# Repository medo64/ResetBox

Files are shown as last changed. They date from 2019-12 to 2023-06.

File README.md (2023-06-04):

### ResetBox

This device will turn off DC power supply if a longer press on external switch
is detected. Status will be communicated on external LED.

#### Operation

Press and hold button for 2 seconds until LED decreases in brightness. Once
button is released, device will reset. If you hold button even longer (additional
10 second after LED has dimmed) power off operation will be cancelled.

#### Set Voltage

Output devices MUST be disconnected during this time unless they can handle
full 20 V.

Unplug USB cable and hold internal button while plugging it back in until ACT
LED stops blinking (about 3 seconds). No you can release button. In config mode,
press internal button once for each voltage step. Once voltage has been
selected, long press internal button to save the value. Once blinking stops,
release the button and device will start normally.

---

*You can check my blog and other projects at [www.medo64.com](https://www.medo64.com/electronics/).*

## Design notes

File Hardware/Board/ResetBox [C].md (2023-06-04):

### ResetBox

Board size: 56.6 x 57.7 mm ~ 4.3 sqin
Voltage: 5-20 V
Current: 3A

#### Parts

|  # | Part | RefDes  | Part Number |
|---:|---|---|---|
|  3 | C 100nF X7R 25V (0805) | C1-C3 | 478-5311-1-ND |
|  2 | C 2.2uF X7R 100V (1206) | C4-C5 | 478-12481-1-ND |
|  8 | DS LED (0805) | DS1-DS8 | 475-1415-1-ND |
|  1 | J USB C 2.0, horizontal | J1 | 2073-USB4085-GF-ACT-ND |
|  2 | J Barrel 2.1x5.5mm | J2-J3 | 839-1514-ND |
| /2 | J MC 1,5/ 2-G-3,81 (2w) *OPTIONAL* | (J2-J3) | ED2808-ND |
|  2 | J Barrel 2.1x5.5mm | J2-J3 | 839-1514-ND |
|  1 | J JST S3B-XH-A (3w) | J4 | 455-2250-ND |
|  1 | Q NPN 40V 100mA (SOT-23) | Q1 | MMBT3904TPMSCT-ND |
|  1 | Q P-MOSFET 30V 4A (SOT-23) | Q1 | DMP3099L-13DICT-ND |
|  1 | R 470 5% 0.125W (0805) | R1 | RMCF0805JT470R |
| 10 | R 3.3K 5% 0.125W (0805) | R2-R11  | RMCF0805JT3K30 |
|  4 | R 10K 5% 0.125W (0805) | R12-R15 | RMCF0805JT10K0 |
|  1 | S Tactile SPST-NO (6x6mm) | S1 | 450-1647-ND |
|  1 | U PIC12F1501-I/SN (SOIC-8) | U1 | PIC12F1501-I/SN-ND |
|  1 | U 74HC238D (SOIC-16) | U2 | 74HC238DCT-ND |
|  1 | VR 3V3 (SOT23-3 B) | VR1 | AP7380-33Y-13DICT-ND |
|  1 | VR CH224K | VR2 | |
|  1 | H 1593KBK | | HM355-ND |
|  4 | H PCB Screw Self-tapping M3 6mm (#4 1/4") | | SR6004-ND |
|  1 | S Momentary {560} | | 1528-2542-ND |
| /2 | P MC 1,5/ 4-ST-3,81 (2w) *OPTIONAL* | | ED2875-ND |

#### Alternative Connectors

As alternative to barrel connectors, one can use block headers. Either one or
the other should be used.

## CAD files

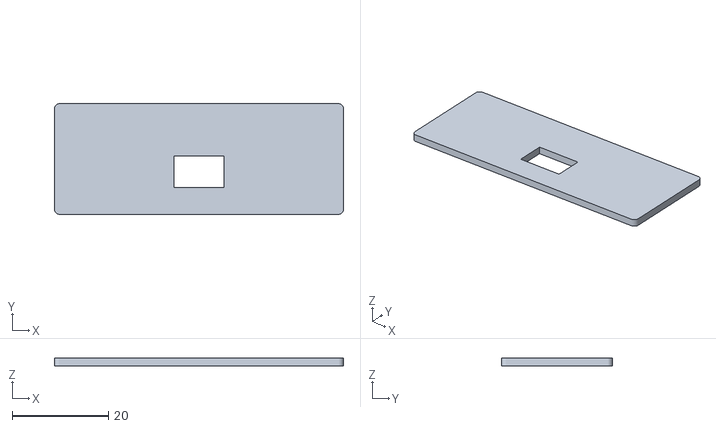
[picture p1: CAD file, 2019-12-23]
Hardware/Board/ResetBox Panel (Front).stl
60.0 x 23.0 x 1.60

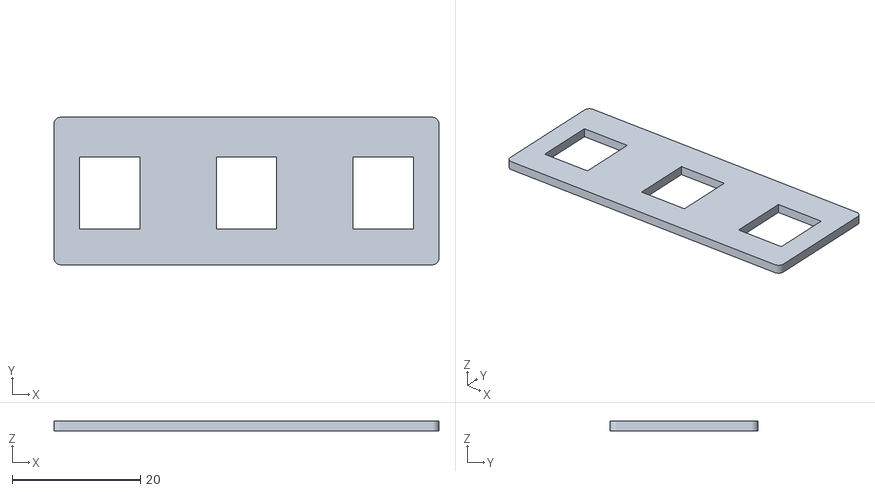
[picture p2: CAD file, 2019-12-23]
Hardware/Board/ResetBox Panel (Back).stl
60.0 x 23.0 x 1.60

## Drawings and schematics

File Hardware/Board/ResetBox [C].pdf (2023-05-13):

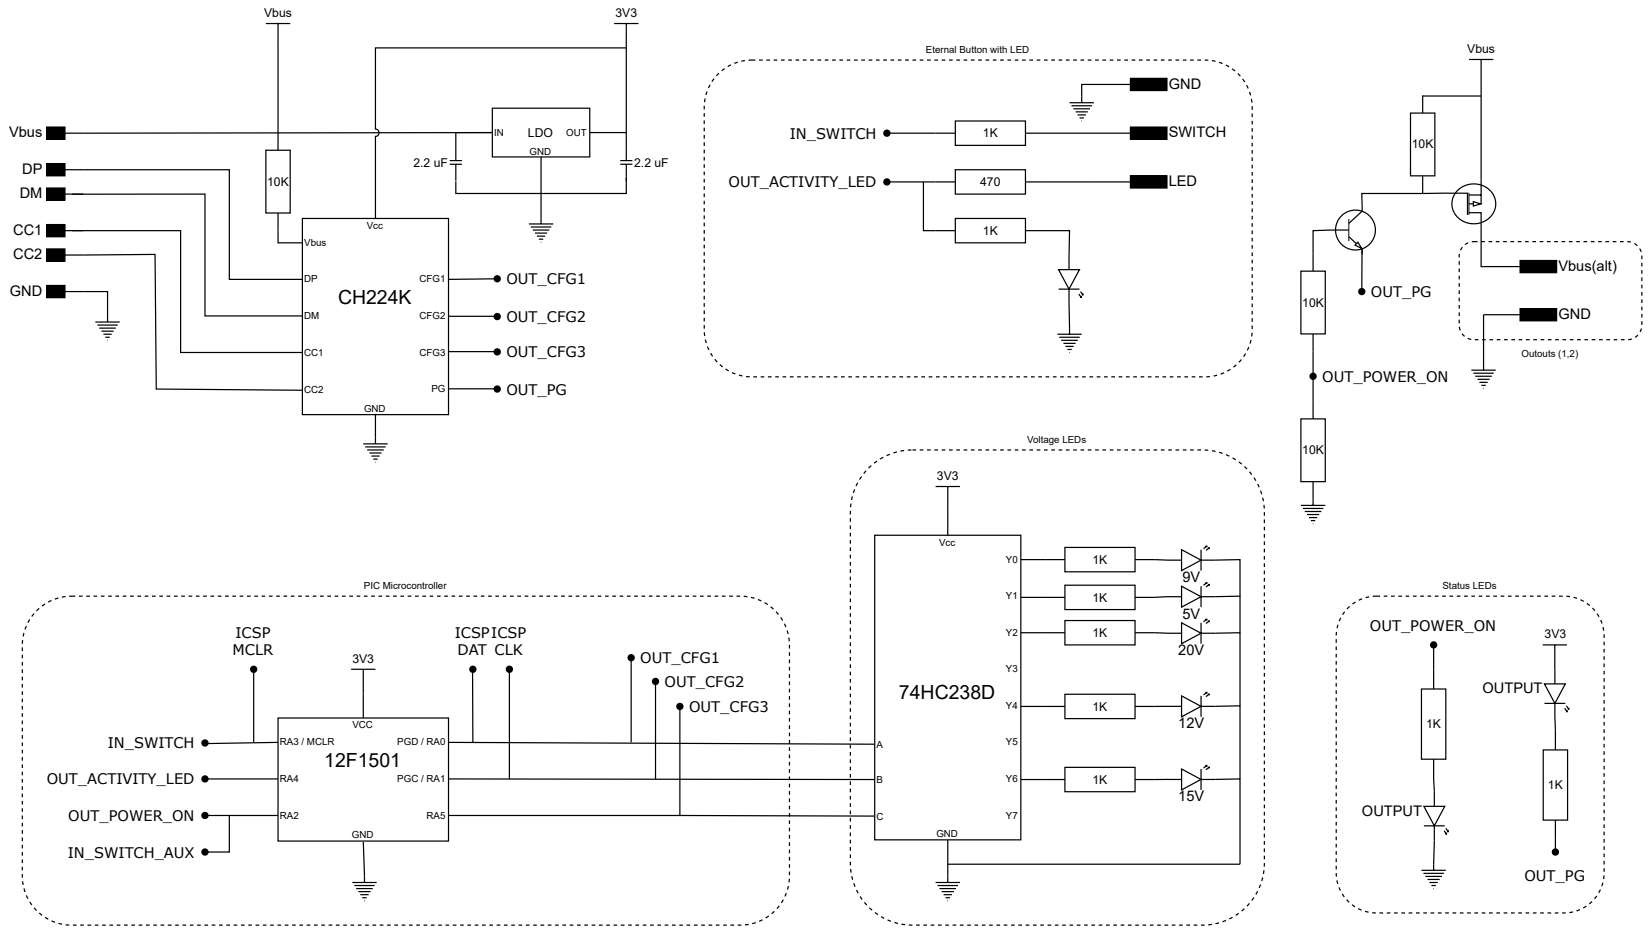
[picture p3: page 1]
PIC Microcontroller; Status LEDs; Voltage LEDs; LDO; GND; OUT; OUT_POWER_ON; OUT_ACTIVITY_LED; IN_SWITCH; OUT_CFG1 OUT_CFG2 OUT_CFG3; LED; SWITCH; Vbus; CFG1; CFG2; CFG3; Vcc; OUT_CFG1; OUT_CFG2; OUT_CFG3; ICSP DAT; ICSP CLK; ICSP MCLR; IN_SWITCH_AUX; OUT_PG; Vbus(alt); Outouts (1,2); OUTPUT; PGD / RA0; PGC / RA1; RA3 / MCLR; VCC

Eternal Button with LED

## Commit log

2019-11-23 Added missing wire
2019-11-24 Reworking box so it works between 9-72V
2019-12-04 Added extra LEDs
2019-12-21 Smaller holes for barrel connector
2019-12-21 Smaller drill holes for barrel connector
2019-12-21 Added screws to list of parts
2019-12-22 Lower LED intensity while button is long pressed
2019-12-22 Added size to barrel connector description
2019-12-23 3D printing files for panels
    [ResetBox Panel (Back).stl, ResetBox Panel (Front).stl]
2019-12-27 Changed button to be NC - for easier wiring
2023-04-07 Added schematics
2023-04-07 Updated schematics
2023-04-11 First go at board redesign to work with type-c
2023-04-13 Added Aux switch resistor
2023-05-12 Updated ICSP footprint
2023-05-12 Added basic 20V code
2023-05-13 Changed CFG switch to use 5V instead of GND
2023-05-13 Removed inline resistors from CFG lines
2023-05-13 Basic code for 20V
2023-05-15 Moved type-C connector outward a little
2023-05-28 Updated board to include two separate connector types
2023-06-04 Cleaned up barrel connector
2023-06-04 Increased LED resistors to 3K3
